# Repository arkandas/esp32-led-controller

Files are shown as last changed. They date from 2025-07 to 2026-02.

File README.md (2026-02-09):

# ESP32 LED Controller 💡

A custom ESP32-based controller for WS2812B/SK6812/WS2814 LED strips with web interface and Alexa integration.

> **Latest Version:** V2 includes 24V RGBW support (WS2814), temperature/humidity monitoring, and enhanced status LEDs.

## Versions

### Version 2
✅ Released - Latest version in `main` branch

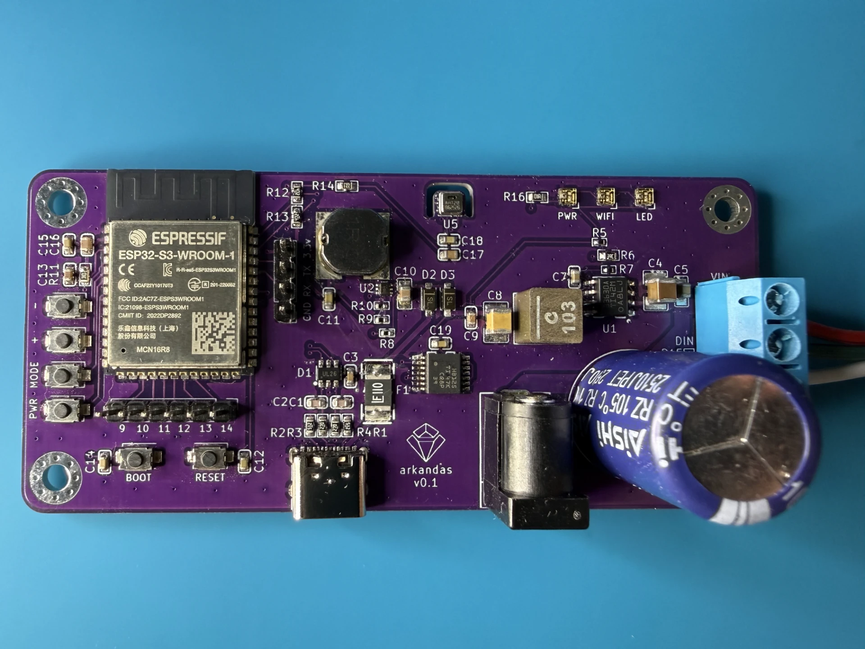
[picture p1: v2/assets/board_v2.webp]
ESP32 LED Controller V2 Board


### Version 1
✅ Released - Tagged as `v1.0.0`

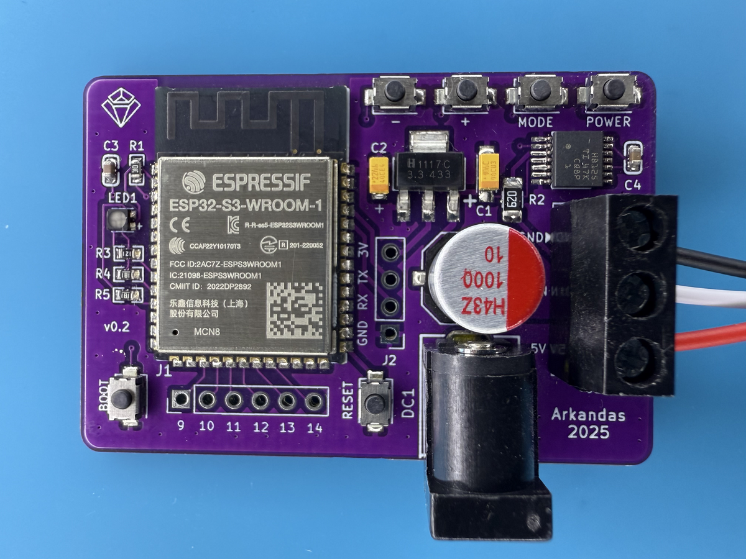
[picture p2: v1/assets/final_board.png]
ESP32 LED Controller Board


---

## Version 2 Documentation

The following documentation applies to **Version 2** of the project. All files are located in the `v2/` directory.

### ✨ Features

- 🎨 **Web Interface** - Real-time control with environment monitoring
- 🗣️ **Alexa Integration** - Voice control support
- 🔘 **Physical Buttons** - Manual brightness/mode control
- 🌈 **Multiple Effects** - Rainbow, chase, breathing animations
- 📱 **Custom Colors** - Full RGBW color picker
- 🌡️ **Temperature & Humidity** - AHT20 sensor for environment monitoring
- 💡 **Status LEDs** - 3x RGB status indicators (Power, WiFi, Strip)
- ⚡ **24V RGBW Support** - WS2814 LED strips with dedicated white channel

### 📁 Project Structure

```
v2/
├── code/                      # Arduino code & web interface
│   └── esp32-ws2814/          # WS2814 (RGBW) version
│       ├── data/              # Web interface files
│       │   ├── index.html     # Main web UI
│       │   ├── style.css      # Styling
│       │   └── app.js         # JavaScript controls
│       └── esp32-ws2814.ino   # Arduino sketch
├── kicad/                     # KiCad PCB project files
└── assets/                    # Board photos & schematics
```

### 🚀 Quick Start

#### Prerequisites

1. **Arduino IDE** with ESP32 support
2. **Required Libraries:**
   - Adafruit NeoPixel (for WS2814 RGBW)
   - FastLED (for status LEDs)
   - FauxmoESP (Alexa integration)
   - AsyncTCP & ESPAsyncWebServer (ESP32 versions)
   - LittleFS (file system)
   - Adafruit AHTX0 (temperature sensor)

#### Installation

1. **Add ESP32 Board Support:**
   ```
   File → Preferences → Additional Board Manager URLs:
   https://raw.githubusercontent.com/espressif/arduino-esp32/gh-pages/package_esp32_index.json
   ```

2. **Board Configuration:**
   - Board: "ESP32S3 Dev Module"
   - Flash Size: "8MB"
   - Partition Scheme: "8M with spiffs (3MB APP/1.5MB SPIFFS)"

3. **Install Libraries** via Library Manager

#### Upload Process

1. **Configure Settings** in the `.ino` file:
   ```cpp
   const char* ssid = "Your_WiFi_Network";
   const char* password = "Your_WiFi_Password";
   #define DEVICE_NAME "Your_Alexa_Device_Name"
   #define WIFI_HOSTNAME "Your_Device_Hostname"
   #define WEB_SERVER_PORT 8080  // Your preferred port
   #define NUM_LEDS 60  // Your LED count
   ```

2. **Upload Web Files:**
   - Install [Arduino LittleFS Upload](https://github.com/earlephilhower/arduino-littlefs-upload) plugin
   - Place the `data` folder in your sketch directory
   - Use: Cmd + Shift + P, then select "Upload LittleFS to Pico/ESP8266/ESP32"

3. **Upload Arduino Sketch** normally

#### Programming via USB

The v2 board uses an **ESP32-S3** with built-in USB - no need for an external USB-to-serial adapter.

**USB Connection:**
- Connect a USB-C cable directly to the ESP32-S3's USB port
- The board will show up as a serial device on your computer

**Arduino IDE USB Configuration:**

To get USB UART working on the Serial Monitor:

1. **Board Settings (Tools menu):**
   - Board: `ESP32S3 Dev Module`
   - USB CDC On Boot: `Enabled` ⚠️ **Important for Serial Monitor**
   - USB Mode: `Hardware CDC and JTAG`
   - Upload Mode: `UART0 / Hardware CDC`
   - Flash Size: `8MB`
   - Partition Scheme: `8M with spiffs (3MB APP/1.5MB SPIFFS)`
   - Upload Speed: `921600` (or lower if uploads fail)

2. **Port Selection:**
   - After connecting USB, select the port showing as ESP32-S3 in Tools → Port
   - macOS: Usually appears as `/dev/cu.usbmodem*`
   - Windows: Usually appears as `COM*`
   - Linux: Usually appears as `/dev/ttyACM*`

**USB CDC On Boot Explained:**
- When `Enabled`, the Serial Monitor will work over USB immediately after boot
- This allows you to see debug output using `Serial.println()` without additional hardware
- The board will enumerate as a USB serial device (CDC - Communications Device Class)

**First-Time Programming:**
1. Connect the board via USB-C
2. The ESP32-S3 should automatically enter bootloader mode when uploading
3. If upload fails, try:
   - Press and hold the `BOOT` button (if available on your board)
   - Click Upload in Arduino IDE
   - Release `BOOT` button when upload starts
4. Open Serial Monitor (Ctrl/Cmd + Shift + M) at `115200` baud to see output

**Troubleshooting:**
- **Port not appearing:** Try a different USB cable (must support data, not just power)
- **Upload fails:** Lower the upload speed to `460800` or `115200`
- **Serial Monitor shows gibberish:** Ensure baud rate is set to `115200` and USB CDC On Boot is enabled

### 🔌 Hardware Connections

| ESP32 Pin | Connection |
|---|---|
| GPIO 40 | WS2814 LED Strip Data |
| GPIO 41 | Status LEDs (3x SK6805-EC20) |
| GPIO 1 | I2C SCL (AHT20 Sensor) |
| GPIO 2 | I2C SDA (AHT20 Sensor) |
| GPIO 4-7  | Control Buttons |

### 🌐 Usage

After successful upload:

1. **WiFi Connection:** Status LEDs flash yellow (5x) when connected
2. **Web Interface:** Visit `http://[ESP32_IP]:[WEB_SERVER_PORT]`

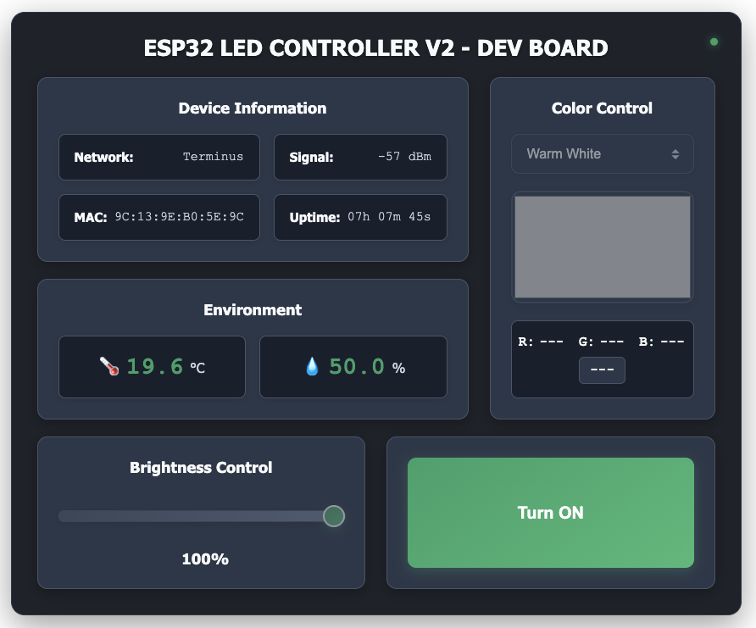
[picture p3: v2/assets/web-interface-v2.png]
Web Interface V2


3. **Alexa:** Say "Alexa, turn on [your device name]"
4. **Buttons:** Physical controls for power/brightness/modes

### 🎛️ Controls

- **Power Button:** Long press (0.5s) to toggle on/off
- **Brightness:** ± buttons adjust in 10% steps
- **Mode Button:** Cycle through colors and effects
- **Web Interface:** Real-time RGBW control, effects, and environment monitoring

### 💡 Status LEDs

The board features 3 RGB status LEDs:
- **LED 1 (Power):** Always green when powered
- **LED 2 (WiFi):** Green when connected, Red when disconnected, Yellow during errors
- **LED 3 (Strip):** Green when strip is on, Red when off

### ⚡ Hardware

Custom PCB design includes:
- ESP32-S3-WROOM-1 (8MB Flash)
- SN74AHCT125 level shifter (3.3V → 5V for WS2814)
- LM1117S-3.3 voltage regulator
- 3x SK6805-EC20 RGB status LEDs
- AHT20 temperature & humidity sensor
- 4 control buttons
- 2.5mm barrel jack power input (24V for WS2814)

### 🔧 Key Differences from V1

- **RGBW Support:** Dedicated white channel for better white light quality
- **24V LED Strips:** Uses WS2814 instead of WS2812B/SK6812
- **Environment Monitoring:** Built-in AHT20 temperature and humidity sensor
- **Improved Status LEDs:** 3x addressable RGB LEDs instead of single common anode LED
- **Enhanced Web Interface:** Shows temperature, humidity, and more device information
- **Configurable Port:** Web server port can be customized

---

## Version 1 Documentation

The following documentation applies to **Version 1** of the project. All files are located in the `v1/` directory.

### ✨ Features

- 🎨 **Web Interface** - Real-time control via browser
- 🗣️ **Alexa Integration** - Voice control support
- 🔘 **Physical Buttons** - Manual brightness/mode control
- 🌈 **Multiple Effects** - Rainbow, chase, breathing animations
- 📱 **Custom Colors** - Full RGB color picker
- 🔧 **Two LED Types** - WS2812B (RGB) and SK6812 (RGBW) support

### 📁 Project Structure

```
v1/
├── code/                       # Arduino code & web interface
│   ├── esp32-ws2812b/          # WS2812B (RGB) version
│   │   ├── data/               # Web interface files
│   │   │   ├── index.html      # Main web UI
│   │   │   ├── style.css       # Styling
│   │   │   └── app.js          # JavaScript controls
│   │   └── esp32-ws2812b.ino   # Arduino sketch
│   └── esp32-sk6812/           # SK6812 (RGBW) version
│       ├── data/               # Web interface files
│       └── esp32-sk6812.ino    # Arduino sketch
├── kicad/                      # KiCad PCB project files
├── gerbers/                    # Manufacturing files
├── datasheets/                 # Component datasheets
├── ibom/                       # Interactive BOM
└── assets/                     # Board photos
```

### 🚀 Quick Start

#### Prerequisites

1. **Arduino IDE** with ESP32 support
2. **Required Libraries:**
   - FastLED (for WS2812B) or Adafruit NeoPixel (for SK6812)
   - FauxmoESP (Alexa integration)
   - AsyncTCP & ESPAsyncWebServer (ESP32 versions)
   - LittleFS (file system)

#### Installation

1. **Add ESP32 Board Support:**
   ```
   File → Preferences → Additional Board Manager URLs:
   https://raw.githubusercontent.com/espressif/arduino-esp32/gh-pages/package_esp32_index.json
   ```

2. **Board Configuration:**
   - Board: "ESP32S3 Dev Module"
   - Flash Size: "8MB"
   - Partition Scheme: "8M with spiffs (3MB APP/1.5MB SPIFFS)"

3. **Install Libraries** via Library Manager

4. **Choose Your LED Type:**
   - `v1/code/esp32-ws2812b/` for standard RGB strips
   - `v1/code/esp32-sk6812/` for RGBW strips with dedicated white channel

#### Upload Process

1. **Configure Settings** in the `.ino` file:
   ```cpp
   const char* ssid = "Your_WiFi_Network";
   const char* password = "Your_WiFi_Password";
   #define DEVICE_NAME "Bedroom Lights"
   #define NUM_LEDS 60  // Your LED count
   ```

2. **Upload Web Files:**
   - Install [Arduino LittleFS Upload](https://github.com/earlephilhower/arduino-littlefs-upload) plugin
   - Place the `data` folder in your sketch directory
   - Use: Cmd + Shift + P, then select "Upload LittleFS to Pico/ESP8266/ESP32"

3. **Upload Arduino Sketch** normally

### 🔌 Hardware Connections

| ESP32 Pin | Connection |
|---|---|
| GPIO 2 | LED Strip Data |
| GPIO 17 | Status LED (Red) |
| GPIO 16 | Status LED (Green) |
| GPIO 18 | Status LED (Blue) |
| GPIO 4-7  | Control Buttons |

### 🌐 Usage

After successful upload:

1. **WiFi Connection:** Board flashes blue → yellow (5x) when connected
2. **Web Interface:** Visit `http://[ESP32_IP]:8080`

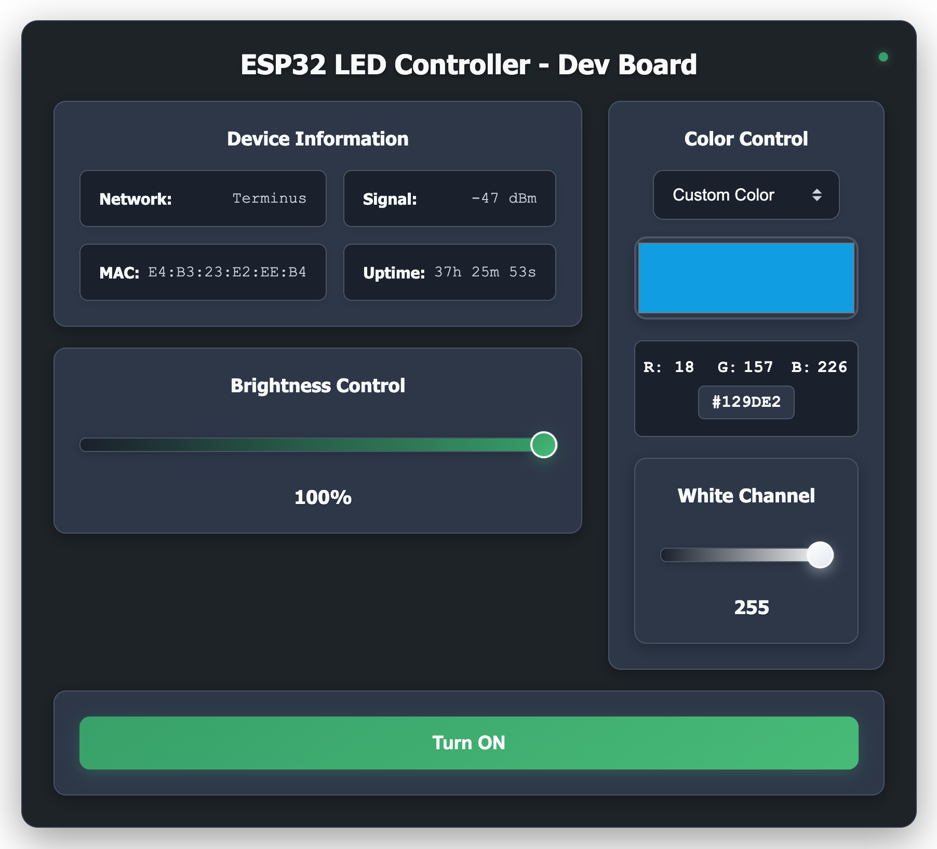
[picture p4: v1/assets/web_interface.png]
Web Interface


3. **Alexa:** Say "Alexa, turn on bedroom lights"
4. **Buttons:** Physical controls for power/brightness/modes

### 🎛️ Controls

- **Power Button:** Long press (0.5s) to toggle on/off
- **Brightness:** ± buttons adjust in 10% steps
- **Mode Button:** Cycle through colors and effects
- **Web Interface:** Real-time RGB control and effects

### 📖 Blog Post

Read the full build story and PCB design process for V1: [ESP32 LED Controller](https://arkandas.com/blog/esp32_led_controller)

### ⚡ Hardware

Custom PCB design includes:
- ESP32-S3-WROOM-1 (8MB Flash)
- SN74AHCT125 level shifter (3.3V → 5V)
- LM1117S-3.3 voltage regulator
- Common anode status LED
- 4 control buttons
- 2.5mm barrel jack power input

### 🛠️ Development

The web interface uses vanilla JavaScript with no external dependencies. All files are served from ESP32's LittleFS for fast loading and offline operation.

## 📄 License

This project is licensed under the MIT License - see the [LICENSE](LICENSE) file for details.

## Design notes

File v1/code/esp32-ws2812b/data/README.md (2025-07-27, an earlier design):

# ESP32 LED Controller - LittleFS Setup

This folder contains the web interface files that need to be uploaded to the ESP32's LittleFS filesystem.

## Files

- `index.html` - Main web interface HTML structure
- `style.css` - Stylesheet for the web interface
- `app.js` - JavaScript for real-time status updates and controls
- `README.md` - This file

## How to Upload to ESP32

### Method 1: Using Arduino IDE with ESP32 LittleFS Data Upload Tool

1. **Install the ESP32 LittleFS Data Upload Tool:**
   - Download from: https://github.com/lorol/arduino-esp32littlefs-plugin
   - Follow the installation instructions for your Arduino IDE version

2. **Upload the data folder:**
   - Place this entire `data` folder in the same directory as your `.ino` file
   - In Arduino IDE, go to `Tools` → `ESP32 LittleFS Data Upload`
   - Wait for the upload to complete

### Method 2: Using PlatformIO

1. **Configure platformio.ini:**
   ```ini
   [env:esp32dev]
   platform = espressif32
   board = esp32dev
   framework = arduino
   board_build.filesystem = littlefs
   ```

2. **Upload filesystem:**
   - Place the `data` folder in your project root
   - Run: `pio run --target uploadfs`

### Method 3: Using ESP32 Web File Manager

1. **Enable file manager in code** (if implemented)
2. **Access web interface** at `http://[ESP32_IP]/files`
3. **Upload files manually** through the web interface

## Features

The web interface provides:

- **Real-time status updates** - No placeholder data, always shows current device state
- **Automatic connection detection** - Disables controls when disconnected
- **Immediate feedback** - Status updates immediately after changes
- **Responsive design** - Works on desktop and mobile devices
- **Error handling** - Clear error messages for connection issues

## Technical Details

- **File system:** LittleFS (Little File System)
- **Update frequency:** Every 2 seconds
- **Fallback:** 404 error if files not found
- **MIME type:** Properly served as `text/html`

## Status Endpoint

The web interface fetches data from `/status` endpoint which returns:

```json
{
  "isPoweredOn": true,
  "brightnessLevel": 8,
  "currentMode": 0
}
```

## Notes

- The web interface will show "Connecting to device..." until the first successful status fetch
- Controls are disabled until a successful connection is established
- All data is fetched live from the ESP32 - no static placeholders are ever shown
- The interface automatically handles reconnection if the ESP32 restarts

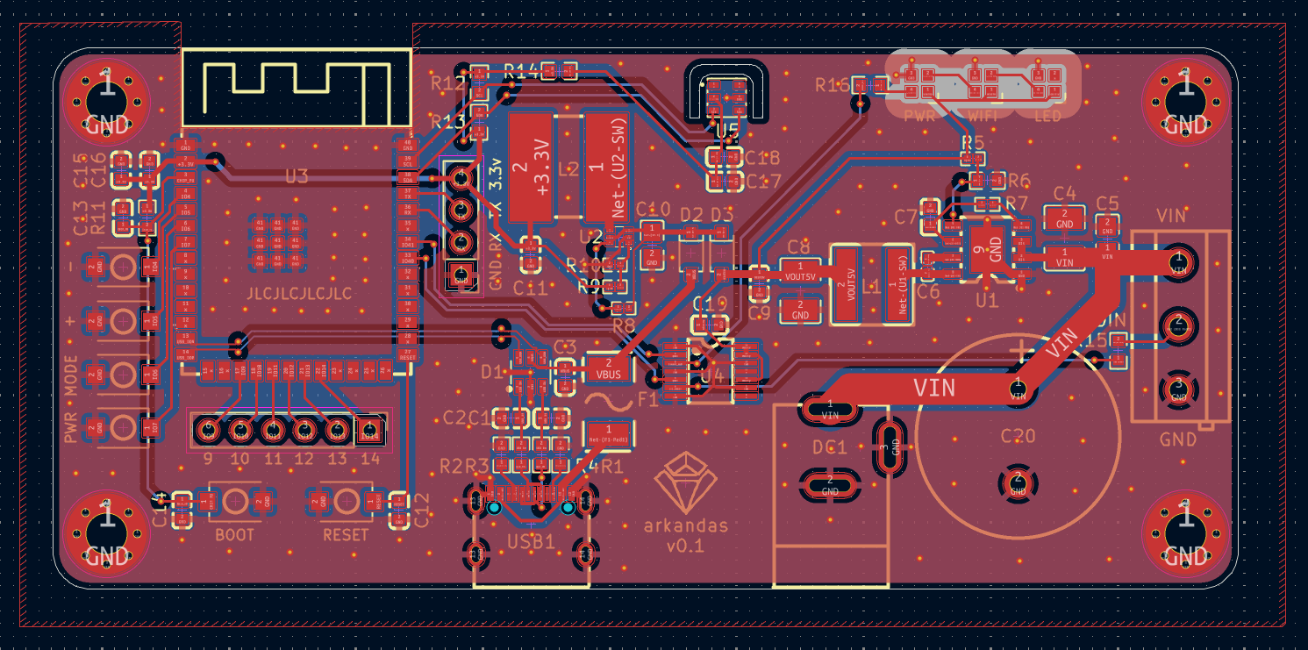
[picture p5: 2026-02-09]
v2/assets/board-esp32-led-controller-v2.png

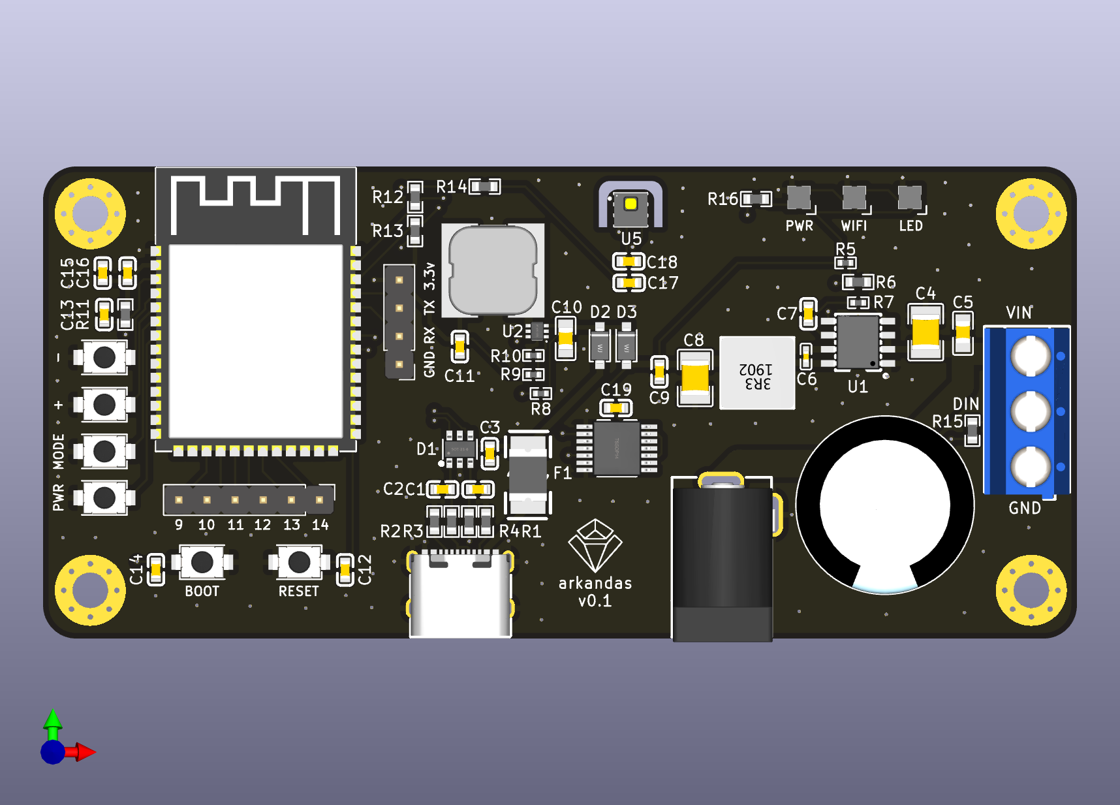
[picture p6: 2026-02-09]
v2/assets/esp32-led-controller-v2.png

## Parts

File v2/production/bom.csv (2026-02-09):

Designator | Footprint | Quantity | Value | LCSC Part #
C1, C2 | C0603 | 2 | 22pf | C1653
C10 | C0805 | 1 | 4.7uF | C1779
C11 | C0603 | 1 | 22uF | C77042
C12, C14, C15, C18, C19 | C0603 | 5 | 0.1uF | C1591
C13 | C0603 | 1 | 1uF | C2918486
C16, C17 | C0603 | 2 | 10uF | C96446
C20 | CAP-TH_BD16.0-P7.50-D1.2-FD | 1 | 1000uF | C383058
C3, C9 | C0603 | 2 | 0.1uF | C14663
C4 | C1210 | 1 | 10uF | C77102
C5 | C0805 | 1 | 220nF | C107131
C6 | C0402 | 1 | 0.1uF | C71629
C7 | C0603 | 1 | 1uF | C696361
C8 | C1210 | 1 | 47uF | C77101
D1 | SOT-23-6_L2.9-W1.6-P0.95-LS2.8-BL | 1 | USBLC6-2SC6 | C7519
D2, D3 | SOD-123_L2.7-W1.7-LS3.8-RD | 2 | B5819W | C5345968
DC1 | DC-IN-TH_DC-005-5A-2.5 | 1 | DC-005-5A-2.5 | C381115
F1 | FUSE-SMD_L4.7-W3.4 | 1 | 1.1A | C163516
J1 | PinHeader_1x04_P2.54mm_Vertical | 1 | UART
J2 | PinHeader_1x06_P2.54mm_Vertical | 1 | GPIO
L1 | IND-SMD_L6.6-W6.4 | 1 | 10uH | C5329540
L2 | IND-SMD_L8.2-W7.9 | 1 | 1uH | C2041438
LED1, LED2, LED3 | LED-SMD_4P-L2.0-W2.0-BR | 3 | SK6805-EC20 | C2890036
R1, R2 | R0603 | 2 | 5.1K | C105580
R10, R5, R7 | R0402 | 3 | 100K | C481918
R11 | R0603 | 1 | 10K | C25804
R12, R13 | R0603 | 2 | 4.7k | C99782
R14 | R0603 | 1 | 220ohm | C22962
R15, R16 | R0603 | 2 | 100ohm | C105588
R3, R4 | R0603 | 2 | 27ohm | C137753
R6 | R0603 | 1 | 24.9K | C137761
R8 | R0402 | 1 | 475K | C2085628
R9 | R0402 | 1 | 453K | C843903
SW1 | SW-SMD_L3.9-W3.0-P4.45 | 1 | RESET | C720477
SW2 | SW-SMD_L3.9-W3.0-P4.45 | 1 | BOOT | C720477
SW3 | SW-SMD_L3.9-W3.0-P4.45 | 1 | - | C720477
SW4 | SW-SMD_L3.9-W3.0-P4.45 | 1 | + | C720477
SW5 | SW-SMD_L3.9-W3.0-P4.45 | 1 | MODE | C720477
SW6 | SW-SMD_L3.9-W3.0-P4.45 | 1 | POWER | C720477
U1 | ESOP-8_L4.9-W3.9-P1.27-LS6.0-TL-EP | 1 | LMR33630ADDAR | C841384
U2 | SOT-563_L1.6-W1.2-P0.50-LS1.6-BR | 1 | TLV62569APDRLR | C398366
U3 | WIRELM-SMD_ESP32-S3-WROOM-1 | 1 | ESP32-S3-WROOM-1(N16R8) | C2913202
U4 | TSSOP-14_L5.0-W4.4-P0.65-LS6.4-BL | 1 | SN74AHCT125PWR | C36365
U5 | SENSOR-SMD_L3.0-W3.0-P1.00-BR | 1 | AHT20_C2757850 | C2757850
U9 | CONN-TH_3P-P5.00_KF301-5.0-3P | 1 | LED_STRIP_CONN | C474882
USB1 | USB-C-SMD_TYPE-C-6PIN-2MD-073 | 1 | TYPE-C 16PIN 2MD(073) | C2765186

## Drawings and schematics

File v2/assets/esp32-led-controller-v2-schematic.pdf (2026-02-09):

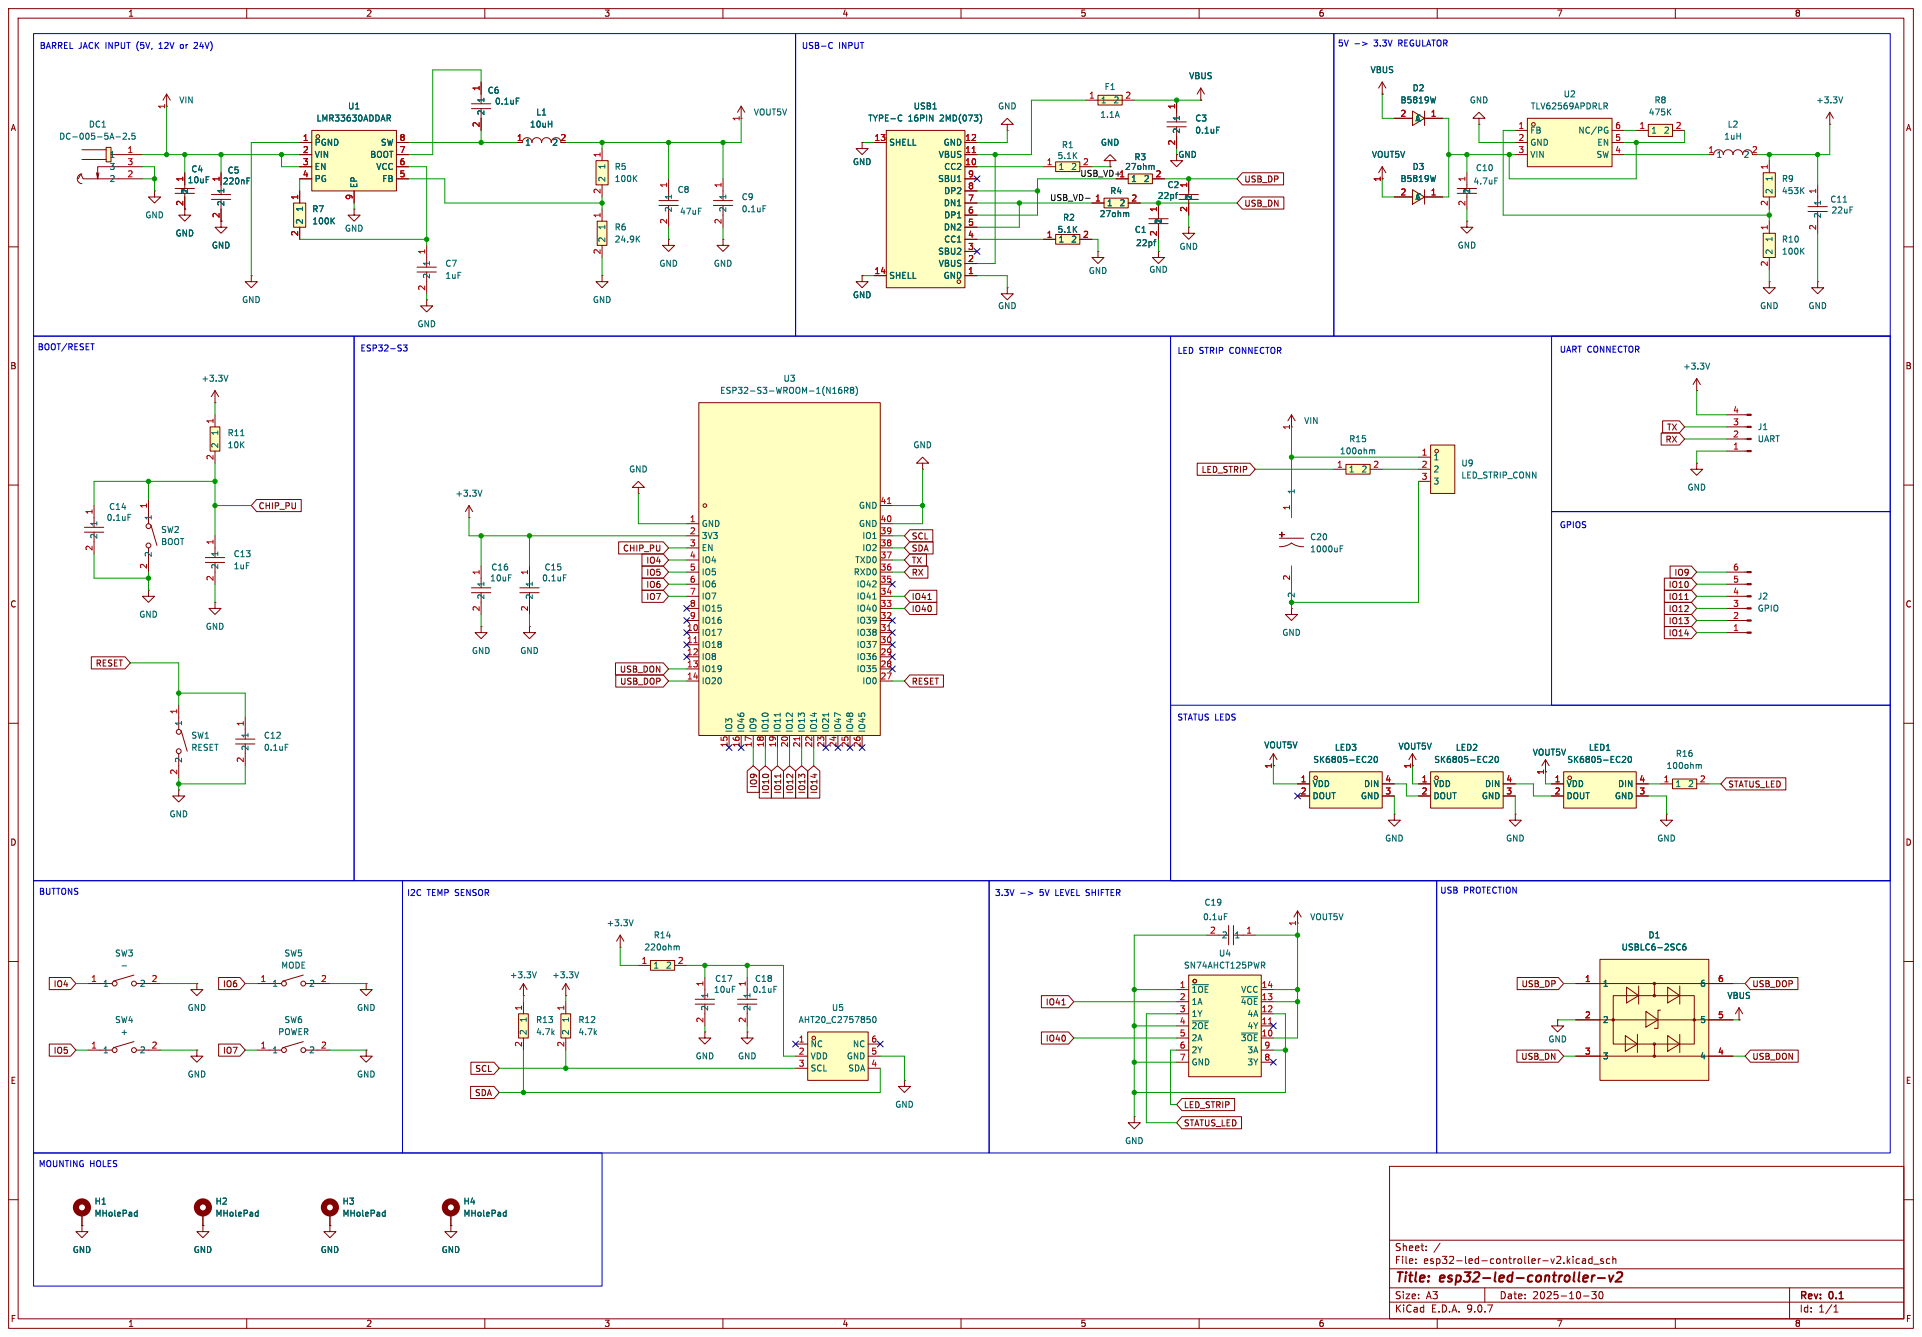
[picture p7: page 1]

9 SW 8 BOOT 7 VCC 6 FB 5 U1
LMR33630ADDAR

2 USB1 TYPE-C 16PIN 2MD(073) GND 1 VBUS 2 SBU2 3 CC1 4 DN2 5 DP1 6 DN1 7 DP2 8 SBU1 9 CC2 10 VBUS 11 GND 12 SHELL 14 SHELL 13 GND GND

9 SW 8 BOOT 7 VCC 6 FB 5 R7

Id: 1/1 Title: esp32-led-controller-v2

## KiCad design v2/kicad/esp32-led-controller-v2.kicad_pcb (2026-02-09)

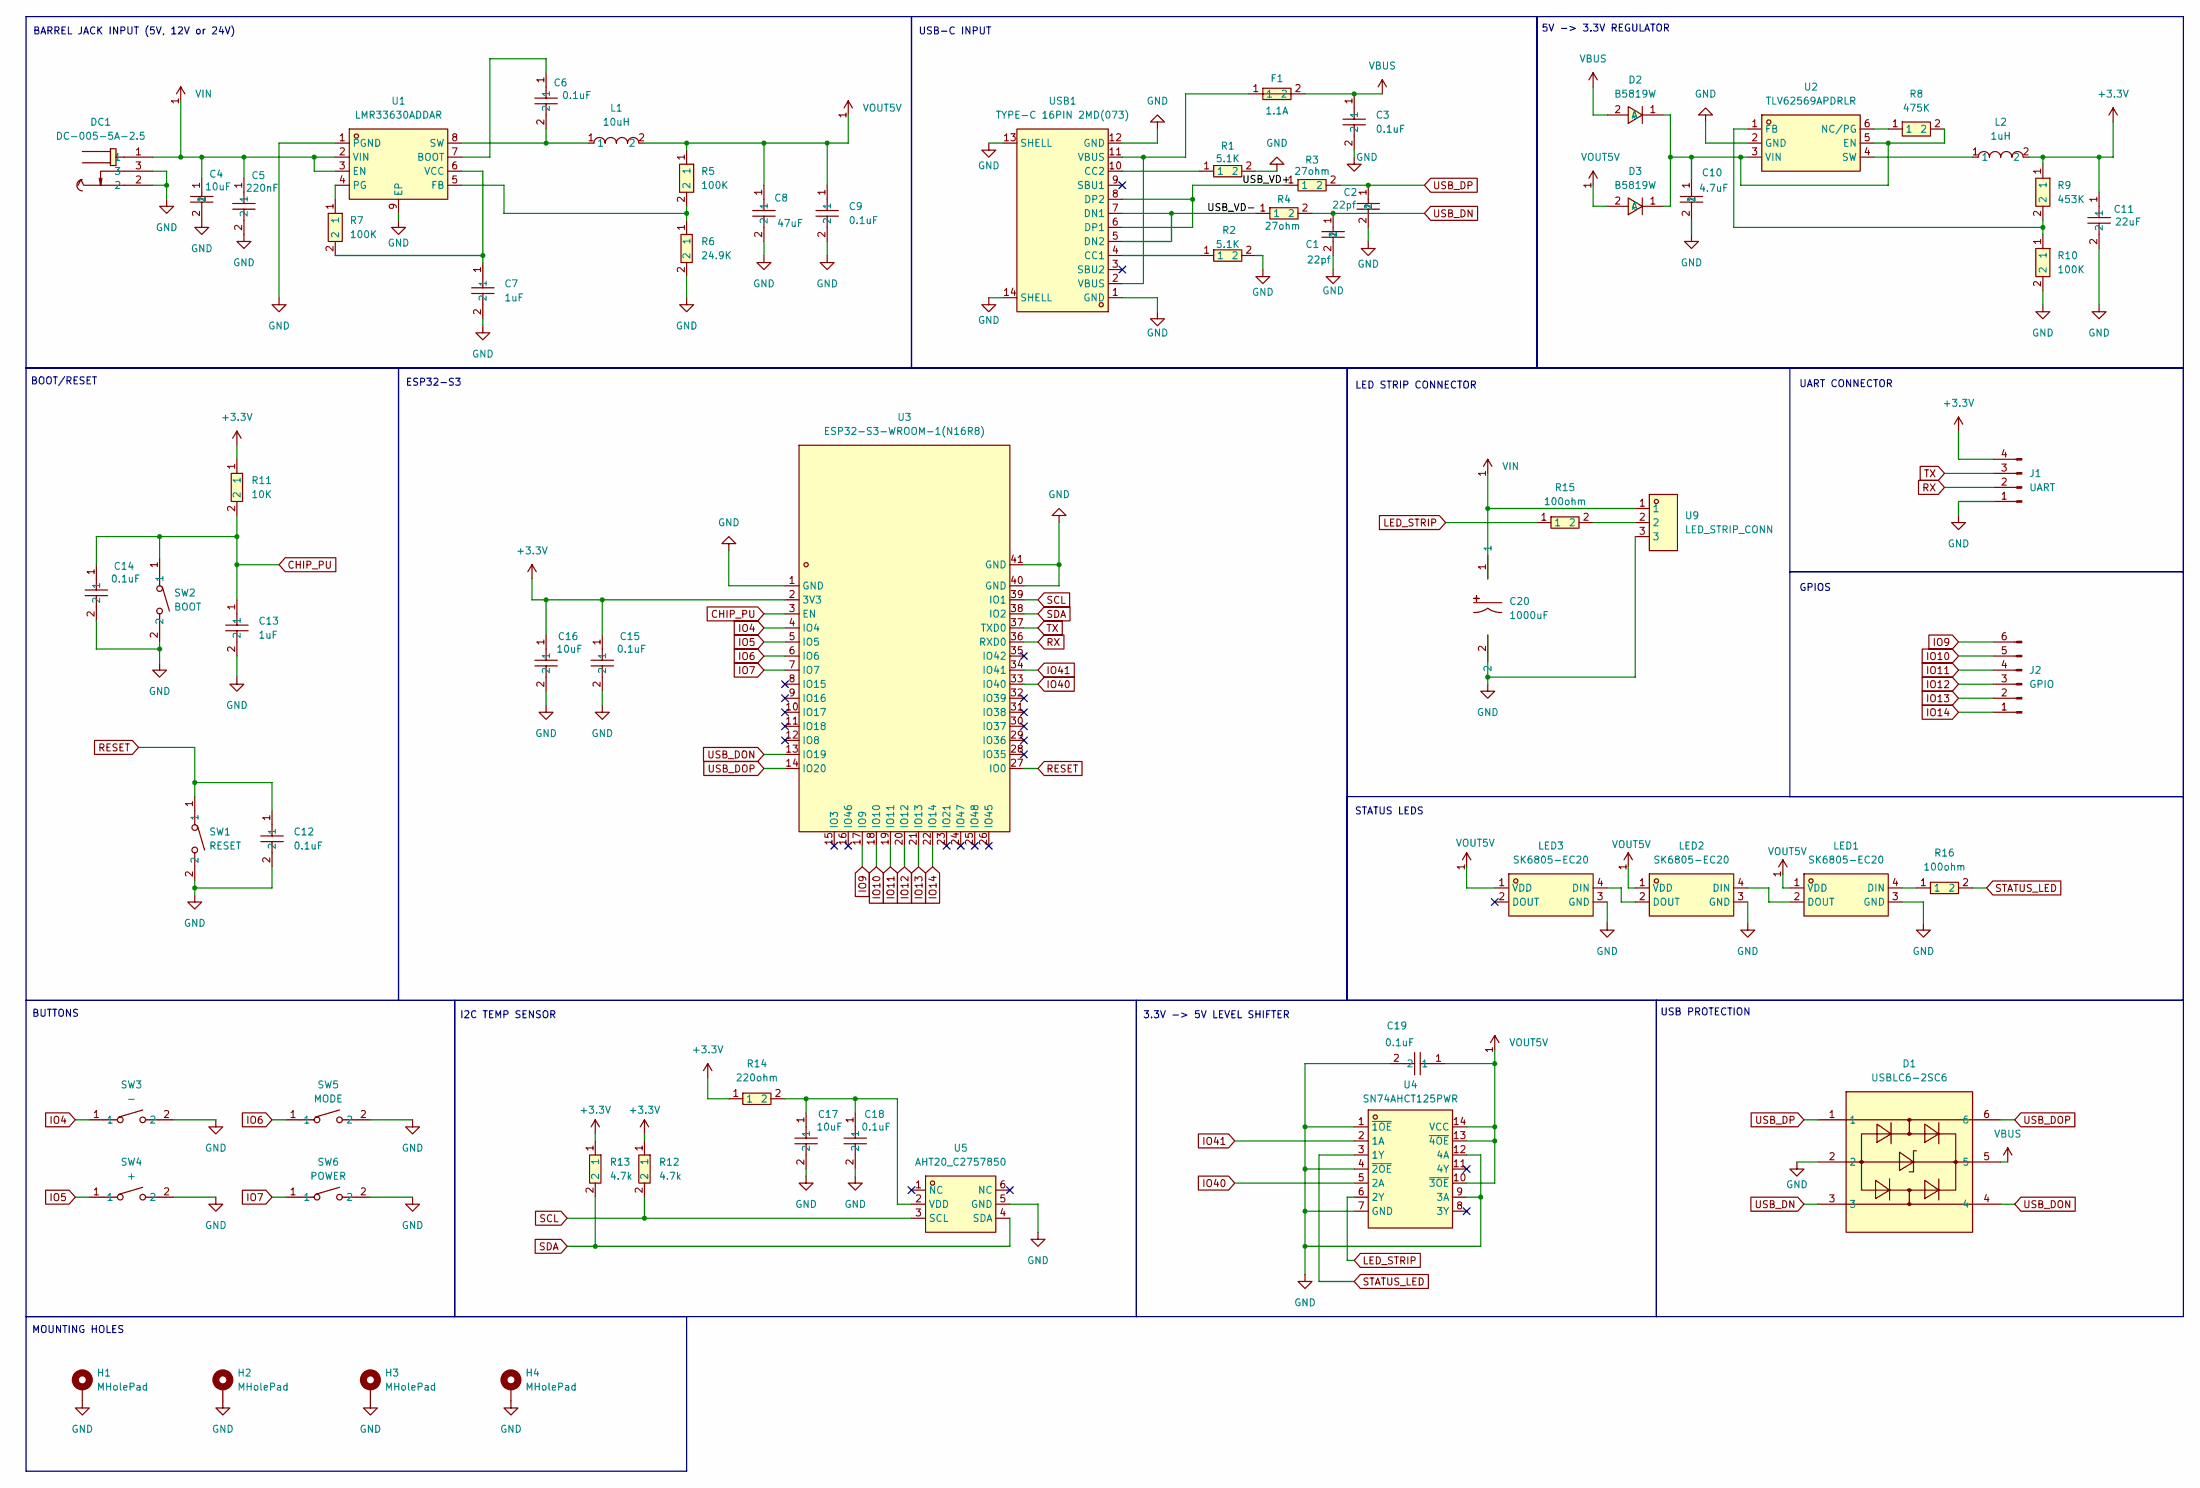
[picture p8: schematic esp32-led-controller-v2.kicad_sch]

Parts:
C1, C2: 22pf; C0603; LCSC Part C1653
C3, C9: 0.1uF; C0603; LCSC Part C14663
C4: 10uF; C1210; LCSC Part C77102
C5: 220nF; C0805; LCSC Part C107131
C6: 0.1uF; C0402; LCSC Part C71629
C7: 1uF; C0603; LCSC Part C696361
C8: 47uF; C1210; LCSC Part C77101
C10: 4.7uF; C0805; LCSC Part C1779
C11: 22uF; C0603; LCSC Part C77042
C12, C14, C15, C18, C19: 0.1uF; C0603; LCSC Part C1591
C13: 1uF; C0603; LCSC Part C2918486
C16, C17: 10uF; C0603; LCSC Part C96446
C20: 1000uF; CAP-TH_BD16.0-P7.50-D1.2-FD; LCSC Part C383058
D1: USBLC6-2SC6; SOT-23-6_L2.9-W1.6-P0.95-LS2.8-BL; LCSC Part C7519
D2, D3: B5819W; SOD-123_L2.7-W1.7-LS3.8-RD; LCSC Part C5345968
DC1: DC-005-5A-2.5; DC-IN-TH_DC-005-5A-2.5; LCSC Part C381115
F1: 1.1A; FUSE-SMD_L4.7-W3.4; LCSC Part C163516
H1, H2, H3, H4: MHolePad; MountingHole_3.2mm_M3_Pad_Via
J1: UART; PinHeader_1x04_P2.54mm_Vertical
J2: GPIO; PinHeader_1x06_P2.54mm_Vertical
L1: 10uH; IND-SMD_L6.6-W6.4; LCSC Part C5329540
L2: 1uH; IND-SMD_L8.2-W7.9; LCSC Part C2041438
LED1, LED2, LED3: SK6805-EC20; LED-SMD_4P-L2.0-W2.0-BR; LCSC Part C2890036
R1, R2: 5.1K; R0603; LCSC Part C105580
R3, R4: 27ohm; R0603; LCSC Part C137753
R5, R7, R10: 100K; R0402; LCSC Part C481918
R6: 24.9K; R0603; LCSC Part C137761
R8: 475K; R0402; LCSC Part C2085628
R9: 453K; R0402; LCSC Part C843903
R11: 10K; R0603; LCSC Part C25804
R12, R13: 4.7k; R0603; LCSC Part C99782
R14: 220ohm; R0603; LCSC Part C22962
R15, R16: 100ohm; R0603; LCSC Part C105588
SW1: RESET; SW-SMD_L3.9-W3.0-P4.45; LCSC Part C720477
SW2: BOOT; SW-SMD_L3.9-W3.0-P4.45; LCSC Part C720477
SW3: -; SW-SMD_L3.9-W3.0-P4.45; LCSC Part C720477
SW4: +; SW-SMD_L3.9-W3.0-P4.45; LCSC Part C720477
SW5: MODE; SW-SMD_L3.9-W3.0-P4.45; LCSC Part C720477
SW6: POWER; SW-SMD_L3.9-W3.0-P4.45; LCSC Part C720477
U1: LMR33630ADDAR; ESOP-8_L4.9-W3.9-P1.27-LS6.0-TL-EP; LCSC Part C841384
U2: TLV62569APDRLR; SOT-563_L1.6-W1.2-P0.50-LS1.6-BR; LCSC Part C398366
U3: ESP32-S3-WROOM-1(N16R8); WIRELM-SMD_ESP32-S3-WROOM-1; LCSC Part C2913202
U4: SN74AHCT125PWR; TSSOP-14_L5.0-W4.4-P0.65-LS6.4-BL; LCSC Part C36365
U5: AHT20_C2757850; SENSOR-SMD_L3.0-W3.0-P1.00-BR; LCSC Part C2757850
U9: LED_STRIP_CONN; CONN-TH_3P-P5.00_KF301-5.0-3P; LCSC Part C474882
USB1: TYPE-C 16PIN 2MD(073); USB-C-SMD_TYPE-C-6PIN-2MD-073; LCSC Part C2765186

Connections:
+3.3V: C11.1, C15.1, C16.1, J1.4, L2.2, R9.1, R11.1, R12.1, R13.1, R14.1, U3.2 (3V3)
/USB_VD+: R3.1, USB1.6 (DP1), USB1.8 (DP2)
/USB_VD-: R4.1, USB1.5 (DN2), USB1.7 (DN1)
CHIP_PU: C13.1, C14.1, R11.2, SW2.1, U3.3 (EN)
GND: C1.2, C2.2, C3.2, C4.2, C5.2, C7.2, C8.2, C9.2, C10.2, C11.2, C12.2, C13.2, C14.2, C15.2, C16.2, C17.2, C18.2, C19.2, C20.2, D1.2, DC1.2, DC1.3, H1.1, H2.1, H3.1, H4.1, J1.1, LED1.3 (GND), LED2.3 (GND), LED3.3 (GND), R1.2, R2.2, R6.2, R10.2, SW1.2, SW2.2, SW3.2, SW4.2, SW5.2, SW6.2, U1.1 (PGND), U1.9 (EP), U2.2 (GND), U3.1 (GND), U3.40 (GND), U3.41 (GND), U4.1 (~1OE), U4.4 (~2OE), U4.7 (GND), U4.9 (3A), U4.12 (4A), U5.5 (GND), U9.3, USB1.1 (GND), USB1.12 (GND), USB1.13 (SHELL), USB1.14 (SHELL)
IO4: SW3.1, U3.4 (IO4)
IO5: SW4.1, U3.5 (IO5)
IO6: SW5.1, U3.6 (IO6)
IO7: SW6.1, U3.7 (IO7)
IO9: J2.6, U3.17 (IO9)
IO10: J2.5, U3.18 (IO10)
IO11: J2.4, U3.19 (IO11)
IO12: J2.3, U3.20 (IO12)
IO13: J2.2, U3.21 (IO13)
IO14: J2.1, U3.22 (IO14)
IO40: U3.33 (IO40), U4.5 (2A)
IO41: U3.34 (IO41), U4.2 (1A)
LED_STRIP: R15.1, U4.6 (2Y)
unnamed: C10.1, D2.1 (C), D3.1 (C), R8.2, U2.3 (VIN), U2.5 (EN)
unnamed: F1.1, USB1.2 (VBUS), USB1.11 (VBUS)
unnamed: LED1.4 (DIN), R16.1
unnamed: LED1.2 (DOUT), LED2.4 (DIN)
unnamed: LED2.2 (DOUT), LED3.4 (DIN)
unnamed: R15.2, U9.2
unnamed: C6.1, U1.7 (BOOT)
unnamed: R5.2, R6.1, U1.5 (FB)
unnamed: R7.1, U1.4 (PG)
unnamed: C6.2, L1.1, U1.8 (SW)
unnamed: C7.1, R7.2, U1.6 (VCC)
unnamed: R9.2, R10.1, U2.1 (FB)
unnamed: R8.1, U2.6 (NC/PG)
unnamed: L2.1, U2.4 (SW)
unnamed: C17.1, C18.1, R14.2, U5.2 (VDD)
unnamed: R2.1, USB1.4 (CC1)
unnamed: R1.1, USB1.10 (CC2)
RESET: C12.1, SW1.1, U3.27 (IO0)
RX: J1.2, U3.36 (RXD0)
SCL: R12.2, U3.39 (IO1), U5.3 (SCL)
SDA: R13.2, U3.38 (IO2), U5.4 (SDA)
STATUS_LED: R16.2, U4.3 (1Y)
TX: J1.3, U3.37 (TXD0)
USB_DN: C1.1, D1.3, R4.2
USB_DON: D1.4, U3.13 (IO19)
USB_DOP: D1.6, U3.14 (IO20)
USB_DP: C2.1, D1.1, R3.2
VBUS: C3.1, D1.5, D2.2 (A), F1.2
VIN: C4.1, C5.1, C20.1, DC1.1, U1.2 (VIN), U1.3 (EN), U9.1
VOUT5V: C8.1, C9.1, C19.1, D3.2 (A), L1.2, LED1.1 (VDD), LED2.1 (VDD), LED3.1 (VDD), R5.1, U4.10 (~3OE), U4.13 (~4OE), U4.14 (VCC)

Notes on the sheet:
MOUNTING HOLES
BOOT/RESET
3.3V -> 5V LEVEL SHIFTER
ESP32-S3
GPIOS
LED STRIP CONNECTOR
I2C TEMP SENSOR
BUTTONS
USB PROTECTION
UART CONNECTOR
BARREL JACK INPUT (5V, 12V or 24V)
5V -> 3.3V REGULATOR
USB-C INPUT
STATUS LEDS

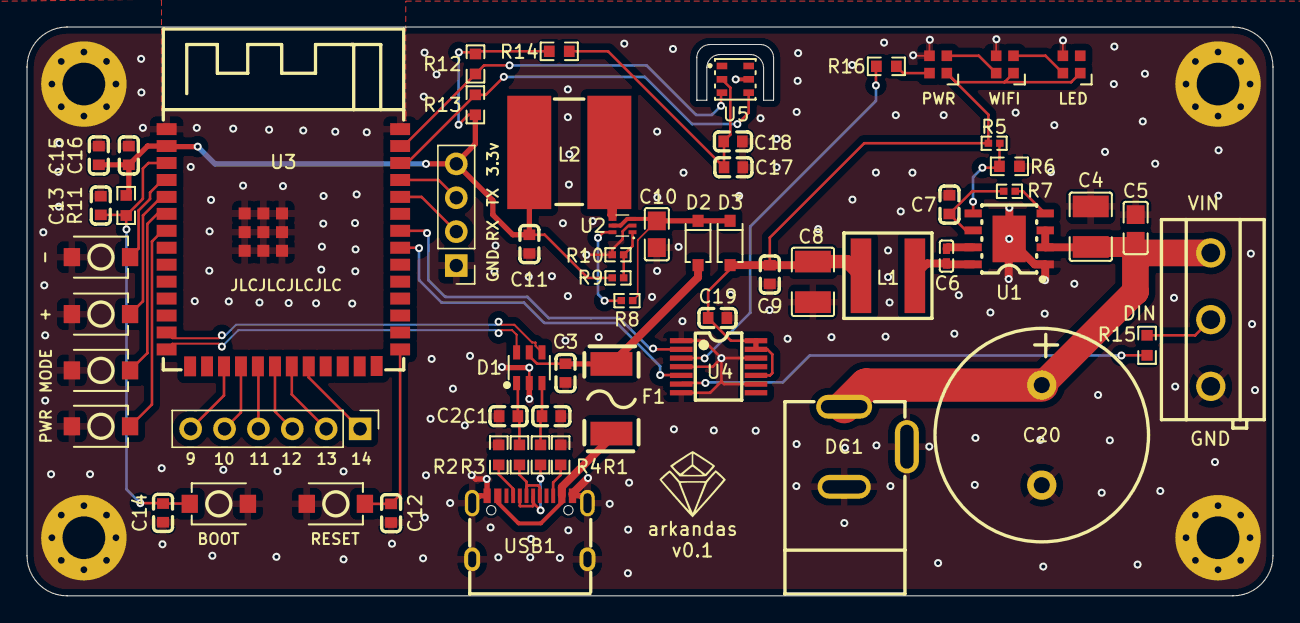
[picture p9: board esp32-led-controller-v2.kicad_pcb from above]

Board: 2 copper layers, 93.4 x 42.6 mm, 65 parts (0 on the bottom side), 48 nets.

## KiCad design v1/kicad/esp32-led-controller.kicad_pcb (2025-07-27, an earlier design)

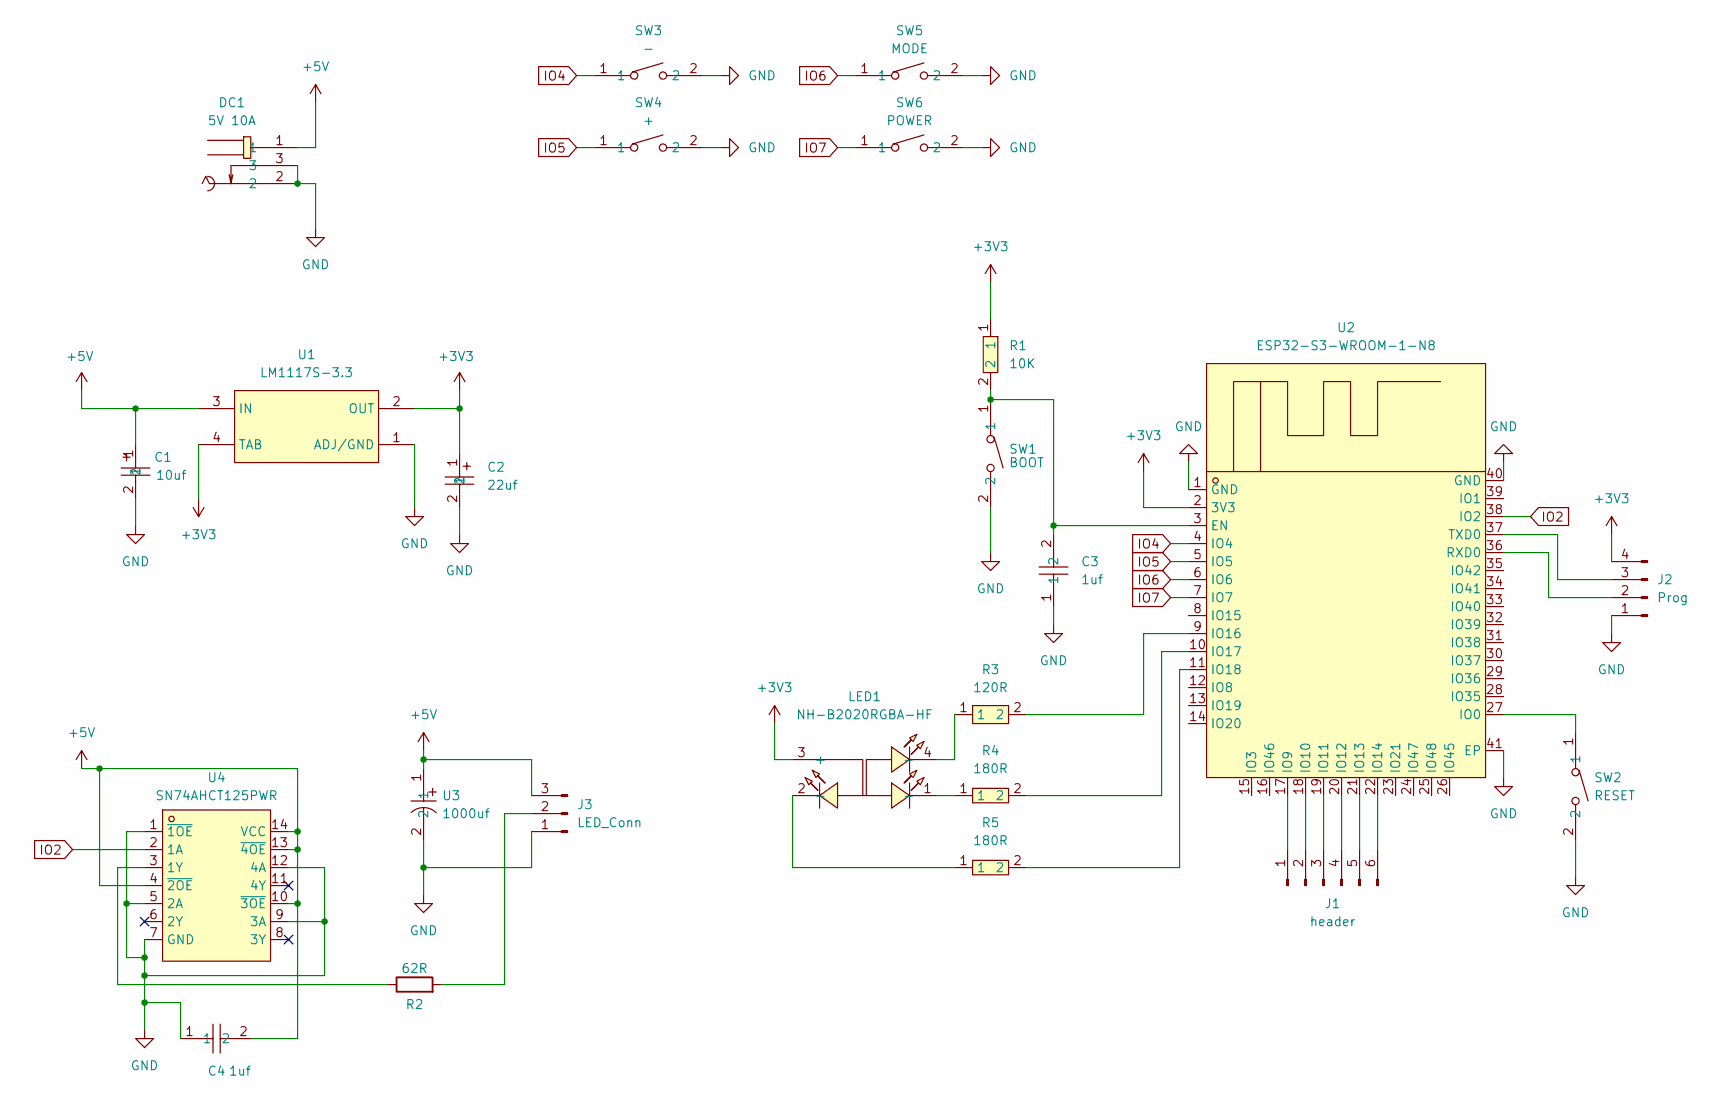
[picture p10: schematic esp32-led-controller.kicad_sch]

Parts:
C1: 10uf; CAP-SMD_L3.2-W1.6-RD-C7171; LCSC Part C7171
C2: 22uf; CASE-A_3216; LCSC Part C11366
C3, C4: 1uf; C0603; LCSC Part C2918486
DC1: 5V 10A; DC-IN-TH_DC-005-5A-2.5; LCSC Part C381115
J1: header; PinHeader_1x06_P2.54mm_Vertical
J2: Prog; PinHeader_1x04_P2.54mm_Vertical
J3: LED_Conn; TerminalBlock_MaiXu_MX126-5.0-03P_1x03_P5.00mm
LED1: NH-B2020RGBA-HF; LED-ARRAY-SMD_4P-L2.1-W2.1-TL_NH-B2020RGBA; LCSC Part C2874116
R1: 10K; R0603; LCSC Part C25804
R2: 62R; R_1206_3216Metric; LCSC Part C3013271
R3: 120R; R0603; LCSC Part C2907096
R4, R5: 180R; R0603; LCSC Part C22828
SW1: BOOT; SW-SMD_L3.9-W3.0-P4.45; LCSC Part C720477
SW2: RESET; SW-SMD_L3.9-W3.0-P4.45; LCSC Part C720477
SW3: -; SW-SMD_L3.9-W3.0-P4.45; LCSC Part C720477
SW4: +; SW-SMD_L3.9-W3.0-P4.45; LCSC Part C720477
SW5: MODE; SW-SMD_L3.9-W3.0-P4.45; LCSC Part C720477
SW6: POWER; SW-SMD_L3.9-W3.0-P4.45; LCSC Part C720477
U1: LM1117S-3.3; SOT-223-3_L6.5-W3.4-P2.30-LS7.0-BR; LCSC Part C126027
U2: ESP32-S3-WROOM-1-N8; WIFIM-SMD_ESP32-S3-WROOM-1-N8; LCSC Part C2913198
U3: 1000uf; CAP-SMD_BD8.0-L8.3-W8.3-LS9.1-FD; LCSC Part C19191929
U4: SN74AHCT125PWR; TSSOP-14_L5.0-W4.4-P0.65-LS6.4-BL; LCSC Part C36365

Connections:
+3V3: C2.1, J2.4, LED1.3 (+), R1.1, U1.2 (OUT), U1.4 (TAB), U2.2 (3V3)
+5V: C1.1, C4.2, DC1.1, J3.3, U1.3 (IN), U3.1, U4.4 (~2OE), U4.10 (~3OE), U4.13 (~4OE), U4.14 (VCC)
GND: C1.2, C2.2, C3.1, C4.1, DC1.2, DC1.3, J2.1, J3.1, SW1.2, SW2.2, SW3.2, SW4.2, SW5.2, SW6.2, U1.1 (ADJ/GND), U2.1 (GND), U2.40 (GND), U2.41 (EP), U3.2, U4.1 (~1OE), U4.5 (2A), U4.7 (GND), U4.9 (3A), U4.12 (4A)
IO2: U2.38 (IO2), U4.2 (1A)
IO4: SW3.1, U2.4 (IO4)
IO5: SW4.1, U2.5 (IO5)
IO6: SW5.1, U2.6 (IO6)
IO7: SW6.1, U2.7 (IO7)
unnamed: J1.1, U2.17 (IO9)
unnamed: J1.2, U2.18 (IO10)
unnamed: J1.3, U2.19 (IO11)
unnamed: J1.4, U2.20 (IO12)
unnamed: J1.5, U2.21 (IO13)
unnamed: J1.6, U2.22 (IO14)
unnamed: J2.2, U2.36 (RXD0)
unnamed: J2.3, U2.37 (TXD0)
unnamed: J3.2, R2.2
unnamed: LED1.1 (-), R4.1
unnamed: LED1.2 (-), R5.1
unnamed: LED1.4 (-), R3.1
unnamed: C3.2, R1.2, SW1.1, U2.3 (EN)
unnamed: SW2.1, U2.27 (IO0)
unnamed: R3.2, U2.9 (IO16)
unnamed: R4.2, U2.10 (IO17)
unnamed: R5.2, U2.11 (IO18)
unnamed: R2.1, U4.3 (1Y)

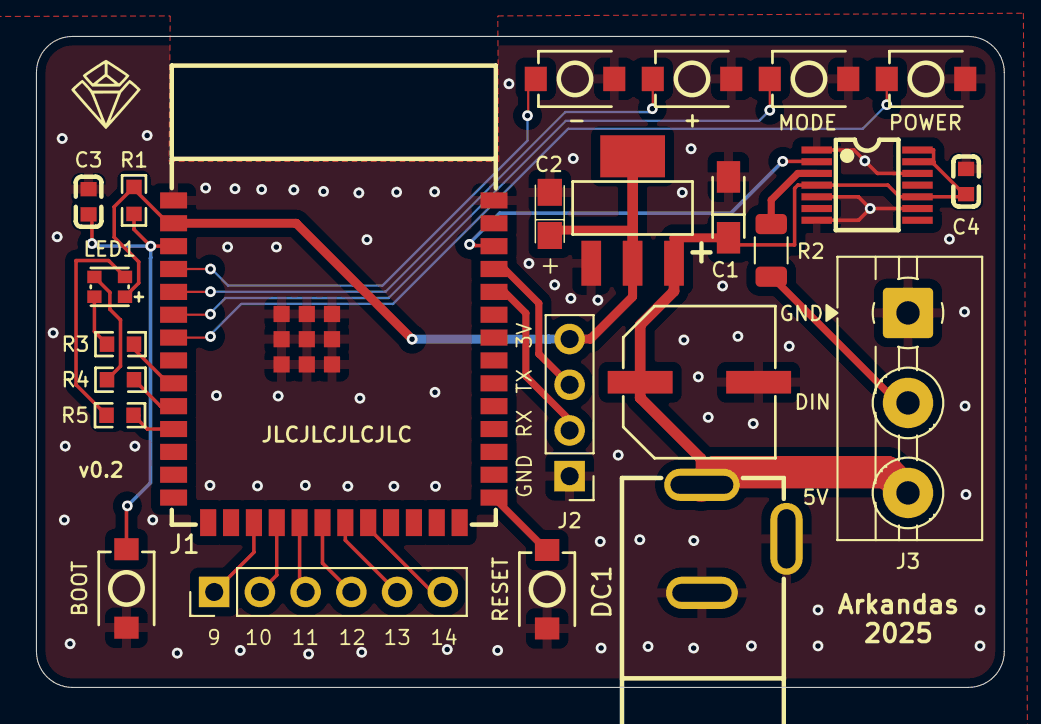
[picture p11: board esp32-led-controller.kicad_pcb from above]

Board: 2 copper layers, 53.8 x 36.2 mm, 24 parts (0 on the bottom side), 26 nets.

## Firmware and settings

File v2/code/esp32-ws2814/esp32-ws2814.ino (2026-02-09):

#include <Arduino.h>
#include <WiFi.h>
#include <ESPAsyncWebServer.h>
#include <Adafruit_NeoPixel.h>
#include <FastLED.h>
#include <fauxmoESP.h>
#include <AsyncTCP.h>
#include <LittleFS.h>
#include <Wire.h>
#include <Adafruit_AHTX0.h>

// WiFi credentials
const char* ssid = "<YOUR_WIFI_SSID>";
const char* password = "<YOUR_WIFI_PASSWORD>";

// Device settings
#define DEVICE_NAME "<YOUR_ALEXA_DEVICE_NAME>"
#define WIFI_HOSTNAME "<YOUR_DEVICE_HOSTNAME>"
#define WEB_SERVER_PORT <YOUR_WEB_SERVER_PORT>

// LED Strip settings (WS2814 24V RGBW on IO40)
#define NUM_LEDS <YOUR_LED_COUNT>
#define LED_STRIP_PIN 40

// Status LEDs settings (3x SK6805-EC20 on IO41)
#define STATUS_LED_PIN 41
#define NUM_STATUS_LEDS 3
#define STATUS_LED_TYPE WS2812
#define STATUS_COLOR_ORDER GRB

// Status LED indices
#define LED_POWER 0    // LED1: Power indicator (always on when powered)
#define LED_WIFI 1     // LED2: WiFi status
#define LED_STRIP 2    // LED3: LED strip on/off status

// I2C pins for AHT20 temperature sensor
#define I2C_SDA 2
#define I2C_SCL 1

// Button pins
#define BTN_MINUS 4  // Brightness decrease
#define BTN_PLUS 5   // Brightness increase
#define BTN_MODE 6   // Mode change
#define BTN_POWER 7  // Power toggle

// Web server on defined port (moved from 80 to avoid conflict with fauxmo)
AsyncWebServer server(WEB_SERVER_PORT);

// Alexa handler
fauxmoESP fauxmo;

// AHT20 temperature sensor
Adafruit_AHTX0 aht;
bool ahtAvailable = false;
float currentTemperature = 0.0;
float currentHumidity = 0.0;
unsigned long lastTempRead = 0;
const unsigned long tempReadInterval = 5000; // Read every 5 seconds

// WiFi connection status
bool wifiConnected = false;
int wifiErrorCode = 0; // 0 = no error, 1 = connection failed, 2 = SSID not found, 3 = timeout

// LED strip (RGBW) using Adafruit NeoPixel
Adafruit_NeoPixel strip(NUM_LEDS, LED_STRIP_PIN, NEO_WRGB + NEO_KHZ800);

// Status LEDs (RGB) using FastLED
CRGB statusLeds[NUM_STATUS_LEDS];

// State variables
bool isPoweredOn = true;
int brightnessLevel = 10;    // Start at full brightness (10 = 100%)
int currentMode = 0;         // Start with white (index 0 in the colorModes array)
unsigned long lastButtonPressTime = 0;
const unsigned long debounceDelay = 200; // Debounce time in milliseconds

// Custom color variables (RGBW)
uint8_t customRed = 255;
uint8_t customGreen = 255;
uint8_t customBlue = 255;
uint8_t customWhite = 0;
bool useCustomColor = false;

// Power button long press variables
bool powerButtonPressed = false;
unsigned long powerButtonPressStartTime = 0;
const unsigned long powerButtonLongPressDelay = 500; // 0.5 seconds for long press

// Error display variables
unsigned long lastErrorBlinkTime = 0;
const int errorBlinkInterval = 500;  // ms
bool errorLedState = false;
int errorBlinkCount = 0;
int errorCycleCount = 0;

// Color definitions for RGBW LEDs (R, G, B, W)
const int MAX_MODES = 10;
uint8_t colorModes[MAX_MODES][4] = {
  {0, 0, 0, 255},       // 0: Pure White (W channel only)
  {255, 0, 0, 0},       // 1: Red
  {0, 255, 0, 0},       // 2: Green
  {0, 0, 255, 0},       // 3: Blue
  {255, 255, 0, 0},     // 4: Yellow
  {255, 0, 255, 0},     // 5: Purple/Magenta
  {0, 255, 255, 0},     // 6: Cyan
  {255, 165, 0, 0},     // 7: Orange
  {255, 255, 255, 255}, // 8: Bright White (RGB + W)
  {0, 0, 0, 0}          // 9: Effects mode (placeholder)
};

// Effect variables
unsigned long lastEffectTime = 0;
const int effectSpeed = 50;
int effectStep = 0;

// Status LED brightness (dimmed for status indication)
const uint8_t STATUS_LED_BRIGHTNESS = 10;  // ~4% brightness

void setup() {
  // Initialize Serial for debugging
  Serial.begin(115200);
  Serial.println("ESP32-S3 LED Controller V2 - WS2814 RGBW & SK6805 Status LEDs");

  // Initialize status LEDs first for error indication
  FastLED.addLeds<STATUS_LED_TYPE, STATUS_LED_PIN, STATUS_COLOR_ORDER>(statusLeds, NUM_STATUS_LEDS);

  // Validate configuration
  if (String(ssid) == "<YOUR_WIFI_SSID>" || String(password) == "<YOUR_WIFI_PASSWORD>" ||
      String(DEVICE_NAME) == "<YOUR_ALEXA_DEVICE_NAME>" || String(WIFI_HOSTNAME) == "<YOUR_DEVICE_HOSTNAME>") {
    Serial.println("ERROR: Please configure your settings in the code!");
    Serial.println("Update ssid, password, DEVICE_NAME, WIFI_HOSTNAME, WEB_SERVER_PORT, and NUM_LEDS.");
    // Flash red on all status LEDs to indicate configuration error
    while(true) {
      fill_solid(statusLeds, NUM_STATUS_LEDS, CRGB::Red);
      FastLED.show();
      delay(500);
      fill_solid(statusLeds, NUM_STATUS_LEDS, CRGB::Black);
      FastLED.show();
      delay(500);
    }
  }

  // Initialize LittleFS
  if (!LittleFS.begin(true)) {
    Serial.println("An error occurred while mounting LittleFS");
    return;
  }
  Serial.println("LittleFS initialized successfully");

  // Initialize I2C for AHT20
  Wire.begin(I2C_SDA, I2C_SCL);

  // Initialize AHT20 temperature sensor
  if (aht.begin()) {
    Serial.println("AHT20 temperature sensor initialized");
    ahtAvailable = true;
    // Read initial temperature
    readTemperature();
  } else {
    Serial.println("WARNING: Could not find AHT20 sensor!");
    ahtAvailable = false;
  }

  // Initialize LED strip (RGBW)
  strip.begin();
  strip.show(); // Initialize all pixels to 'off'

  // Set initial status LED state - Power LED on (green)
  fill_solid(statusLeds, NUM_STATUS_LEDS, CRGB::Black);
  statusLeds[LED_POWER] = CRGB(0, STATUS_LED_BRIGHTNESS, 0);  // Power LED green
  FastLED.show();

  // Initialize buttons with pullup resistors
  pinMode(BTN_MINUS, INPUT_PULLUP);
  pinMode(BTN_PLUS, INPUT_PULLUP);
  pinMode(BTN_MODE, INPUT_PULLUP);
  pinMode(BTN_POWER, INPUT_PULLUP);

  // Connect to WiFi
  connectToWiFi();

  if (wifiConnected) {
    // Set up Alexa first
    Serial.println("Setting up Alexa...");

    // Initialize fauxmo - it will handle Alexa discovery automatically
    fauxmo.createServer(true);  // Create internal TCP server for Alexa communication
    fauxmo.setPort(80);         // Port 80 required for gen3 Alexa devices
    fauxmo.enable(true);        // Enable after WiFi is connected
    fauxmo.addDevice(DEVICE_NAME);
    Serial.printf("Fauxmo device '%s' added and enabled\r\n", DEVICE_NAME);

    // Set the callback
    fauxmo.onSetState([](unsigned char device_id, const char * device_name, bool state, unsigned char value) {
        Serial.printf("[ALEXA] Device #%d (%s) state: %s\r\n", device_id, device_name, state ? "ON" : "OFF");

        if (strcmp(device_name, DEVICE_NAME) == 0) {
            if (state) {
                // Turn on lights with white color at max brightness
                isPoweredOn = true;
                currentMode = 0;  // Pure White mode
                brightnessLevel = 10;  // Max brightness
                updateLEDStrip();
            } else {
                // Turn off lights
                isPoweredOn = false;
                setStripColor(0, 0, 0, 0);
                strip.show();
            }
            updateStatusLEDs();
        }
    });

    Serial.println("Alexa integration setup complete");

    // Then set up web server
    setupWebServer();
  }

  // Show initial state
  updateStatusLEDs();
  updateLEDStrip();
}

void loop() {
  // Handle WiFi error codes with LED flashes if not connected
  if (!wifiConnected && wifiErrorCode > 0) {
    displayErrorCode();
  } else {
    // Process normal operation
    // Check all button states
    checkButtons();

    if (wifiConnected) {
      // Handle Alexa requests
      fauxmo.handle();

      // Debug message every 30 seconds
      static unsigned long lastMsg = 0;
      if (millis() - lastMsg > 30000) {
        lastMsg = millis();
        Serial.printf("Alexa device '%s' is ready. IP: %s\r\n", DEVICE_NAME, WiFi.localIP().toString().c_str());
        Serial.printf("Web interface available at: http://%s:%d\r\n", WiFi.localIP().toString().c_str(), WEB_SERVER_PORT);
      }
    }

    // Update status LEDs based on power state
    updateStatusLEDs();

    // Update LED strip effects if needed
    unsigned long currentMillis = millis();
    if (isPoweredOn && currentMillis - lastEffectTime > effectSpeed) {
      updateLEDStripEffects();
      lastEffectTime = currentMillis;
    }

    // Read temperature periodically
    if (ahtAvailable && currentMillis - lastTempRead > tempReadInterval) {
      readTemperature();
      lastTempRead = currentMillis;
    }
  }

  // Small delay to reduce CPU usage
  delay(10);
}

void readTemperature() {
  if (!ahtAvailable) return;

  sensors_event_t humidity, temp;
  if (aht.getEvent(&humidity, &temp)) {
    currentTemperature = temp.temperature;
    currentHumidity = humidity.relative_humidity;
    Serial.printf("Temperature: %.1f°C, Humidity: %.1f%%\r\n", currentTemperature, currentHumidity);
  }
}

// Helper function to set all strip LEDs to one RGBW color
void setStripColor(uint8_t r, uint8_t g, uint8_t b, uint8_t w) {
  for (int i = 0; i < NUM_LEDS; i++) {
    strip.setPixelColor(i, strip.Color(r, g, b, w));
  }
}

void connectToWiFi() {
  Serial.print("Connecting to WiFi: ");
  Serial.println(ssid);

  // Set custom hostname (this is what appears on your router)
  WiFi.setHostname(WIFI_HOSTNAME);
  Serial.printf("WiFi hostname set to: %s\r\n", WIFI_HOSTNAME);

  // Set status LEDs during connection attempt
  // Power LED stays green, WiFi LED blue (connecting), Strip LED off
  statusLeds[LED_POWER] = CRGB(0, STATUS_LED_BRIGHTNESS, 0);  // Power: Green
  statusLeds[LED_WIFI] = CRGB(0, 0, STATUS_LED_BRIGHTNESS);   // WiFi: Blue (connecting)
  statusLeds[LED_STRIP] = CRGB::Black;                        // Strip: Off
  FastLED.show();

  // Set LED strip to blue during connection attempt
  setStripColor(0, 0, 255, 0);
  strip.setBrightness(255);
  strip.show();

  // Connect to WiFi
  WiFi.begin(ssid, password);

  // Wait for connection with timeout
  int connectionAttempts = 0;
  while (WiFi.status() != WL_CONNECTED && connectionAttempts < 20) { // 10 second timeout
    delay(500);
    Serial.print(".");
    connectionAttempts++;
  }

  if (WiFi.status() == WL_CONNECTED) {
    Serial.println("");
    Serial.println("WiFi connected successfully");
    Serial.print("IP address: ");
    Serial.println(WiFi.localIP());
    wifiConnected = true;
    wifiErrorCode = 0;

    // Flash yellow on all status LEDs and strip five times to indicate success
    for (int i = 0; i < 5; i++) {
      // Yellow on all status LEDs
      fill_solid(statusLeds, NUM_STATUS_LEDS, CRGB(STATUS_LED_BRIGHTNESS, STATUS_LED_BRIGHTNESS, 0));
      FastLED.show();

      // Flash LED strip yellow (R+G, no W)
      setStripColor(255, 255, 0, 0);
      strip.show();
      delay(200);

      // All off
      fill_solid(statusLeds, NUM_STATUS_LEDS, CRGB::Black);
      FastLED.show();

      setStripColor(0, 0, 0, 0);
      strip.show();
      delay(200);
    }
  } else {
    Serial.println("");
    Serial.println("Failed to connect to WiFi");
    wifiConnected = false;

    // Set LED strip to red to indicate failure
    setStripColor(255, 0, 0, 0);
    strip.show();

    // Set WiFi status LED to red
    statusLeds[LED_WIFI] = CRGB(STATUS_LED_BRIGHTNESS, 0, 0);  // WiFi: Red (error)
    FastLED.show();

    if (WiFi.status() == WL_NO_SSID_AVAIL) {
      Serial.println("SSID not found");
      wifiErrorCode = 2;
    } else if (WiFi.status() == WL_CONNECT_FAILED) {
      Serial.println("Connection failed - check password");
      wifiErrorCode = 1;
    } else {
      Serial.println("Connection timeout");
      wifiErrorCode = 3;
    }
  }
}

void setupWebServer() {
  // Set up web server routes
  server.on("/", HTTP_GET, handleRoot);
  server.on("/control", HTTP_GET, handleControl);
  server.on("/toggle", HTTP_GET, handleToggle);
  server.on("/brightness", HTTP_GET, handleBrightness);
  server.on("/mode", HTTP_GET, handleMode);
  server.on("/status", HTTP_GET, handleStatus);
  server.on("/color", HTTP_GET, handleCustomColor);

  // Serve static files from LittleFS
  server.on("/style.css", HTTP_GET, [](AsyncWebServerRequest *request) {
    if (LittleFS.exists("/style.css")) {
      request->send(LittleFS, "/style.css", "text/css");
    } else {
      request->send(404, "text/plain", "CSS file not found");
    }
  });

  server.on("/app.js", HTTP_GET, [](AsyncWebServerRequest *request) {
    if (LittleFS.exists("/app.js")) {
      request->send(LittleFS, "/app.js", "application/javascript");
    } else {
      request->send(404, "text/plain", "JavaScript file not found");
    }
  });

  // Start server
  server.begin();
  Serial.printf("HTTP server started on port %d\r\n", WEB_SERVER_PORT);
  Serial.printf("Web interface: http://%s:%d\r\n", WiFi.localIP().toString().c_str(), WEB_SERVER_PORT);
}

void handleRoot(AsyncWebServerRequest *request) {
  // Serve the HTML file from LittleFS
  if (LittleFS.exists("/index.html")) {
    request->send(LittleFS, "/index.html", "text/html");
  } else {
    Serial.println("ERROR: index.html not found in LittleFS");
    request->send(404, "text/plain", "File not found. Please upload the data folder to LittleFS.");
  }
}

void handleControl(AsyncWebServerRequest *request) {
  // Simple control interface
  String html = "<html><body>";
  html += "<h1>WS2814 RGBW LED Control</h1>";
  html += "<p>Power: <a href='/toggle'>Toggle</a></p>";
  html += "<p>Brightness: ";
  for (int i = 1; i <= 10; i++) {
    html += "<a href='/brightness?level=" + String(i) + "'>" + String(i*10) + "%</a> ";
  }
  html += "</p>";
  html += "<p>Mode: ";
  for (int i = 0; i < MAX_MODES; i++) {
    html += "<a href='/mode?mode=" + String(i) + "'>" + String(i) + "</a> ";
  }
  html += "</p>";
  html += "</body></html>";
  request->send(200, "text/html", html);
}

void handleToggle(AsyncWebServerRequest *request) {
  isPoweredOn = !isPoweredOn;
  updateStatusLEDs();
  updateLEDStrip();
  request->send(200, "text/plain", "OK");
}

void handleBrightness(AsyncWebServerRequest *request) {
  if (request->hasArg("level")) {
    int level = request->arg("level").toInt();
    if (level >= 1 && level <= 10) {
      brightnessLevel = level;
      updateLEDStrip();
    }
  }
  request->send(200, "text/plain", "OK");
}

void handleMode(AsyncWebServerRequest *request) {
  if (request->hasArg("mode")) {
    int mode = request->arg("mode").toInt();
    if (mode >= 0 && mode < MAX_MODES) {
      currentMode = mode;
      useCustomColor = false;  // Disable custom color when selecting preset mode
      updateLEDStrip();
    }
  }
  request->send(200, "text/plain", "OK");
}

void handleStatus(AsyncWebServerRequest *request) {
  String status = "{";
  status += "\"isPoweredOn\":" + String(isPoweredOn ? "true" : "false") + ",";
  status += "\"brightnessLevel\":" + String(brightnessLevel) + ",";
  status += "\"currentMode\":" + String(currentMode) + ",";
  status += "\"deviceName\":\"" + String(DEVICE_NAME) + "\",";
  status += "\"macAddress\":\"" + WiFi.macAddress() + "\",";
  status += "\"wifiSSID\":\"" + String(ssid) + "\",";
  status += "\"signalStrength\":" + String(WiFi.RSSI()) + ",";
  status += "\"uptime\":" + String(millis() / 1000) + ",";
  status += "\"useCustomColor\":" + String(useCustomColor ? "true" : "false") + ",";
  status += "\"customRed\":" + String(customRed) + ",";
  status += "\"customGreen\":" + String(customGreen) + ",";
  status += "\"customBlue\":" + String(customBlue) + ",";
  status += "\"customWhite\":" + String(customWhite) + ",";
  status += "\"temperature\":" + String(currentTemperature, 1) + ",";
  status += "\"humidity\":" + String(currentHumidity, 1) + ",";
  status += "\"sensorAvailable\":" + String(ahtAvailable ? "true" : "false");
  status += "}";
  request->send(200, "application/json", status);
}

void handleCustomColor(AsyncWebServerRequest *request) {
  if (request->hasArg("r") && request->hasArg("g") && request->hasArg("b")) {
    int r = request->arg("r").toInt();
    int g = request->arg("g").toInt();
    int b = request->arg("b").toInt();
    int w = request->hasArg("w") ? request->arg("w").toInt() : 0;

    // Validate RGBW values
    if (r >= 0 && r <= 255 && g >= 0 && g <= 255 && b >= 0 && b <= 255 && w >= 0 && w <= 255) {
      customRed = r;
      customGreen = g;
      customBlue = b;
      customWhite = w;
      useCustomColor = true;
      updateLEDStrip();
    }
  }
  request->send(200, "text/plain", "OK");
}

void checkButtons() {
  // Only process regular button presses after debounce delay
  unsigned long currentMillis = millis();

  // Handle power button with long press
  if (digitalRead(BTN_POWER) == LOW) {
    // If button was not previously pressed, record the time
    if (!powerButtonPressed) {
      powerButtonPressed = true;
      powerButtonPressStartTime = currentMillis;
    }
    // Check if the button has been pressed long enough
    else if (currentMillis - powerButtonPressStartTime >= powerButtonLongPressDelay) {
      // Long press detected - toggle power
      isPoweredOn = !isPoweredOn;
      Serial.print("Power: ");
      Serial.println(isPoweredOn ? "ON" : "OFF");

      // Reset state to prevent multiple toggles
      powerButtonPressed = false;
      lastButtonPressTime = currentMillis;
      updateStatusLEDs();
      updateLEDStrip();
    }
  } else {
    // Button released
    powerButtonPressed = false;
  }

  // Only process other buttons after debounce delay
  if (currentMillis - lastButtonPressTime < debounceDelay) {
    return;
  }

  // Check minus button (decrease brightness)
  if (digitalRead(BTN_MINUS) == LOW) {
    brightnessLevel = max(1, brightnessLevel - 1);
    Serial.print("Brightness: ");
    Serial.println(brightnessLevel * 10);
    lastButtonPressTime = currentMillis;
    updateLEDStrip();
  }

  // Check plus button (increase brightness)
  if (digitalRead(BTN_PLUS) == LOW) {
    brightnessLevel = min(10, brightnessLevel + 1);
    Serial.print("Brightness: ");
    Serial.println(brightnessLevel * 10);
    lastButtonPressTime = currentMillis;
    updateLEDStrip();
  }

  // Check mode button (change color)
  if (digitalRead(BTN_MODE) == LOW) {
    currentMode = (currentMode + 1) % MAX_MODES;
    useCustomColor = false;  // Disable custom color when changing modes via button
    Serial.print("Mode: ");
    Serial.println(currentMode);
    lastButtonPressTime = currentMillis;
    updateLEDStrip();
  }
}

void displayErrorCode() {
  unsigned long currentMillis = millis();

  // Check if it's time to toggle the LED
  if (currentMillis - lastErrorBlinkTime >= errorBlinkInterval) {
    lastErrorBlinkTime = currentMillis;

    // Toggle LED state
    errorLedState = !errorLedState;
    errorBlinkCount++;

    // Yellow flash for WiFi LED during error
    if (errorLedState) {
      // Power LED stays green
      statusLeds[LED_POWER] = CRGB(0, STATUS_LED_BRIGHTNESS, 0);
      // WiFi LED yellow (error indication)
      statusLeds[LED_WIFI] = CRGB(STATUS_LED_BRIGHTNESS, STATUS_LED_BRIGHTNESS, 0);
      // Strip status LED off
      statusLeds[LED_STRIP] = CRGB::Black;
    } else {
      // Power LED stays green
      statusLeds[LED_POWER] = CRGB(0, STATUS_LED_BRIGHTNESS, 0);
      // WiFi LED off
      statusLeds[LED_WIFI] = CRGB::Black;
      // Strip status LED off
      statusLeds[LED_STRIP] = CRGB::Black;
    }
    FastLED.show();

    // After 60 blinks (about 30 seconds), try to reconnect
    if (errorBlinkCount >= 60) {
      errorBlinkCount = 0;
      connectToWiFi();
    }
  }
}

void updateStatusLEDs() {
  // LED1 (Power): Always green when powered
  statusLeds[LED_POWER] = CRGB(0, STATUS_LED_BRIGHTNESS, 0);

  // LED2 (WiFi): Green if connected, Red if not
  if (wifiConnected) {
    statusLeds[LED_WIFI] = CRGB(0, STATUS_LED_BRIGHTNESS, 0);  // Green
  } else {
    statusLeds[LED_WIFI] = CRGB(STATUS_LED_BRIGHTNESS, 0, 0);  // Red
  }

  // LED3 (Strip): Green if strip is on, Red if off
  if (isPoweredOn) {
    statusLeds[LED_STRIP] = CRGB(0, STATUS_LED_BRIGHTNESS, 0);  // Green
  } else {
    statusLeds[LED_STRIP] = CRGB(STATUS_LED_BRIGHTNESS, 0, 0);  // Red
  }

  FastLED.show();
}

void updateLEDStrip() {
  // Calculate brightness (map 1-10 to 25-255)
  uint8_t brightness = map(brightnessLevel, 1, 10, 25, 255);
  strip.setBrightness(brightness);

  if (!isPoweredOn) {
    // Turn off all LEDs on strip
    setStripColor(0, 0, 0, 0);
    strip.show();
    return;
  }

  // Apply color based on mode or custom color
  if (useCustomColor) {
    // Use custom RGBW color
    setStripColor(customRed, customGreen, customBlue, customWhite);
  } else if (currentMode < MAX_MODES - 1) {
    // Use predefined color mode (not effects mode)
    setStripColor(colorModes[currentMode][0], colorModes[currentMode][1],
                  colorModes[currentMode][2], colorModes[currentMode][3]);
  }

  // Show the changes
  strip.show();

  // Debug output
  if (useCustomColor) {
    Serial.print("LED Strip Update - Custom Color: R=");
    Serial.print(customRed);
    Serial.print(", G=");
    Serial.print(customGreen);
    Serial.print(", B=");
    Serial.print(customBlue);
    Serial.print(", W=");
    Serial.print(customWhite);
  } else {
    Serial.print("LED Strip Update - Mode: ");
    Serial.print(currentMode);
  }
  Serial.print(", Brightness: ");
  Serial.println(brightnessLevel * 10);
}
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

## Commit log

2025-07-27 First release
    [bom.csv, designators.csv, esp32-led-controller.kicad_pcb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]
2025-10-30 v2 first revision
    [bom.csv, designators.csv, esp32-led-controller-v2.kicad_pcb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]
